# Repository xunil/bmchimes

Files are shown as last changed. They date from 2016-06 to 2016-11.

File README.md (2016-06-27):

Controller firmware for ESP8266 modules for Burning Man chimes project.

Using RtcDS3231 library https://github.com/Makuna/Rtc/

TODO:
* WiFi improvements
  * Add config keys for at least 3 WiFi networks and SSIDs
  * Attempt to join each in series for 20 seconds at a time
  * If all three fail, become AP instead
  * Add option to go straight to AP mode
* Add ADC measurement and recording for battery voltage
* Defaults for config

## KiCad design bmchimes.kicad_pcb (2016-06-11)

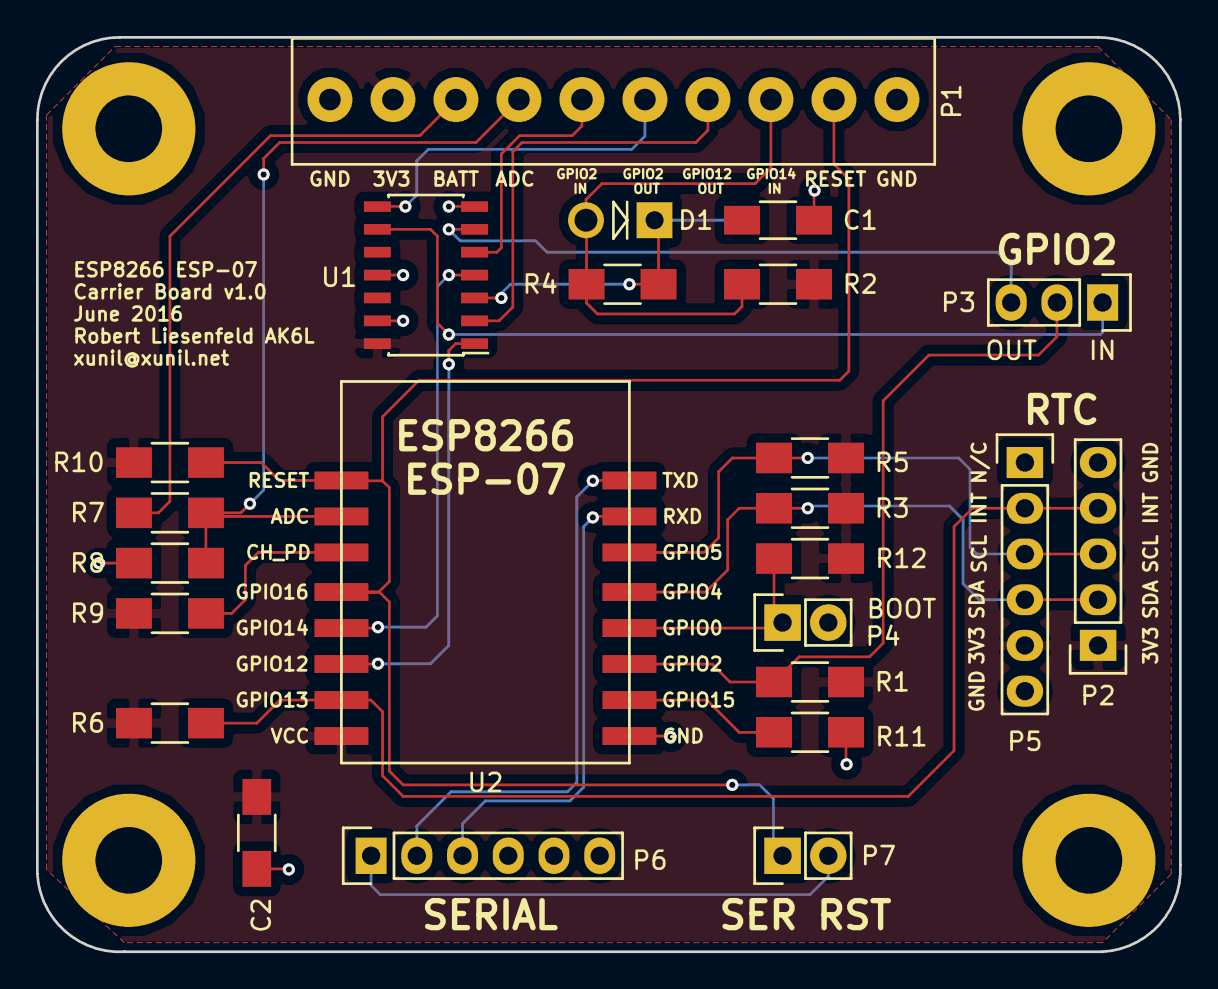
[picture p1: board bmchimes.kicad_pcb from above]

Board: 2 copper layers, 63.5 x 50.8 mm, 28 parts (0 on the bottom side), 24 nets.

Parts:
C1, C2: C; C_1206_HandSoldering
D1: D; Diode_DO-41_SOD81_Vertical_AnodeUp
P1: CONN_01X10; Adafruit_3.5mm_Terminal_Block
P2: CONN_01X05; Pin_Header_Straight_1x05
P3: CONN_02X03; Pin_Header_Straight_1x03
P4, P7: CONN_01X02; Pin_Header_Straight_1x02
P5, P6: CONN_01X06; Pin_Header_Straight_1x06
P8, P9, P10, P11: CONN_01X01; MountingHole_3.7mm_Pad
R1, R2, R3, R4, R5, R6, R7, R8, R9, R10, R11, R12: R; R_1206_HandSoldering
U1: 74HC7014; SOIC-14_3.9x8.7mm_Pitch1.27mm
U2: ESP07

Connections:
3V3: C2.1, P1.2, P2.1, P5.5, R1.1, R2.2, R3.1, R5.1, R6.1, R9.1, R10.1, R12.1, U1.14, U2.16
ADC: P1.4, R7.2, R8.1, U2.10
BATT: P1.3, R7.1
GND: C1.2, C2.2, P1.1, P1.10, P2.5, P4.2, P5.6, P6.6, P8.1, P9.1, P10.1, P11.1, R8.2, R11.2, U1.7, U1.11, U1.13, U2.1
GPIO2: P3.2, R1.2, U2.3
GPIO2_IN: P1.5, U1.5
GPIO2_IN_ST: P3.3, U1.6
GPIO2_OUT: P3.1, U1.9
GPIO2_OUT_ST: P1.6, U1.8
GPIO4: P2.2, P5.4, R3.2, U2.5
GPIO5: P2.3, P5.3, R5.2, U2.6
GPIO12: U1.1, U2.14
GPIO12_OUT: P1.7, U1.2
GPIO13: P2.4, P5.2, R6.2, U2.15
GPIO14: U1.4, U2.13
GPIO14_IN: D1.2, P1.8, R2.1, R4.2
GPIO14_IN_DB: C1.1, D1.1, R4.1, U1.3
unnamed: P4.1, R12.2, U2.4
unnamed: R9.2, U2.11
unnamed: R11.1, U2.2
RESET: P1.9, P7.1, R10.2, U2.9, U2.12
RESET_SER: P6.1, P7.2
RXD: P6.3, U2.7
TXD: P6.2, U2.8

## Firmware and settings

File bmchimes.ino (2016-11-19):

#include <ESP8266WiFi.h>
#include <WiFiClient.h>
#include <ESP8266mDNS.h>
#include <ESP8266SSDP.h>
#include <ESP8266WebServer.h>
#include <WiFiUdp.h>
#include <ArduinoOTA.h>
#include <Wire.h>
#include <time.h>
#include "FS.h"
#include <RtcDS3231.h>
#include <pgmspace.h>
#include "TeeSerial.h"
#include "StringStream.h"

// Uncomment to enable 15 minute chime, comment #undef below
// #define FIFTEEN_MINUTE_CHIME 1
// Disable 15-minute chime
#undef FIFTEEN_MINUTE_CHIME
// Uncomment to enable initial chimes, comment #undef below
// #define STRIKE_INITIAL_CHIMES 1
// Disable initial chime (used when chimes were installed around the man)
#undef STRIKE_INITIAL_CHIMES

// Allows streaming output (<< syntax)
template<class T> inline Print &operator <<(Print &obj, T arg) { obj.print(arg); return obj; }

const int heartbeatPin = 2;
const int rtcAlarmPin = 13;
const int chimePin = 12;
const int chimeStopSwitchPin = 14;
const int statsInterval = 1;
const int statsLinesPerDay = 24 * (60 / statsInterval);

struct BMChimeConfig {
  String deviceDescription;
  String wiFiSSID;
  String wiFiPassword;
  // From ESP8266WiFi.h
  WiFiMode wiFiMode;
  bool connectWiFiAtReset;
  bool sleepEnabled;
  uint16_t wakeEveryNSeconds;
  uint16_t stayAwakeSeconds;
  uint16_t chimeEveryNSeconds; 
  uint16_t chimeStopTimeout; 
  uint16_t chimeCount;
  uint16_t chimeNumber;
  uint16_t chimeCycleSeconds;
  uint16_t chimeInterInitialSeconds;
  bool chimeEnabled;
  bool heartbeatEnabled;
} config;

char ssid[64];
char password[64];
const int led = 2;

RtcDS3231 Rtc;
ESP8266WebServer server(80);

uint16_t sleepDuration = 0;
RtcDateTime wakeAlarmDateTime;
RtcDateTime sleepAlarmDateTime;
RtcDateTime chimeAlarmDateTime;
uint32_t chimeStartMillis = 0;
uint32_t chimeStopMillis = 0;
uint16_t lastChimeDurationMillis = 0;

bool chiming = false;
#define CHIME_INITIAL 0
#define CHIME_SECOND 1
#define CHIME_THIRD 2
#define CHIME_HOUR 3
#define NUM_CHIME_STATES 4
#define MAX_CHIME_SCHEDULE 15
#define INVALID_TIME 0xffffffff
time_t chimeSchedule[MAX_CHIME_SCHEDULE];

bool shouldCollectStats = false;
volatile bool chimingWasEnabled = false;
volatile bool chimeStopSwitchFlag = false;
volatile bool alarmInterruptFlag = false;

const int heartbeatBlipDuration = 50; // In milliseconds
const int heartbeatBlipInterval = 5 * 1000; // In milliseconds
uint32_t millisAtHeartbeatReset;
uint32_t millisAtLastHeartbeatBlip;
uint8_t heartbeatBlipCount = 0;
int heartbeatPinState = LOW;
uint8_t heartbeatBlipMax = 2 * 2; // 2 blinks - on, off, on, off, hence the multiply by 2

// Utility functions
void alarmISR() {
  alarmInterruptFlag = true;
}

void chimeStopSwitchISR() {
  chimeStopSwitchFlag = true;
}

void printStringAsHexDump(String str) {
  char buf[64];
  str.toCharArray(buf, 64);
  for (int i = 0; i < str.length(); i++) {
    TeeSerial0.print(buf[i], HEX);
    TeeSerial0 << " ";
  }
}

void printlnStringAsHexDump(String str) {
  printStringAsHexDump(str);
  TeeSerial0 << "\n";
}

void dateTimeStringFromRtcDateTime(RtcDateTime rtcDateTime, String& dateTimeBuf) {
  char datestring[20];
  snprintf_P(datestring, 
    20,
    PSTR("%02u/%02u/%04u %02u:%02u:%02u"),
    rtcDateTime.Month(),
    rtcDateTime.Day(),
    rtcDateTime.Year(),
    rtcDateTime.Hour(),
    rtcDateTime.Minute(),
    rtcDateTime.Second()
  );

  dateTimeBuf = String(datestring);
}

void getRtcDateTimeString(String& dateTimeBuf) {
  RtcDateTime now = Rtc.GetDateTime();
  dateTimeStringFromRtcDateTime(now, dateTimeBuf);
}

void getNtpDateTimeString(String& dateTimeBuf) {
  struct tm *tmp;
  time_t systemTime = time(nullptr);
  tmp = localtime(&systemTime);

  RtcDateTime systemRtcDateTime = RtcDateTime(
    tmp->tm_year + 1900,
    tmp->tm_mon + 1,
    tmp->tm_mday,
    tmp->tm_hour,
    tmp->tm_min,
    tmp->tm_sec
  );
  dateTimeStringFromRtcDateTime(systemRtcDateTime, dateTimeBuf);
}

uint16_t secondsTilNextN(uint16_t N, RtcDateTime &startingFrom) {
  // 16 bit return value should be sufficient; we will chime or wake at least once an hour.
  uint16_t seconds = ((N - (startingFrom.Minute() % N)) - 1) * 60;
  seconds += 60 - startingFrom.Second();

  return seconds;
}

bool alarmFired(DS3231AlarmFlag& flag) {
  bool wasAlarmed = false;
  if (alarmInterruptFlag) { // check our flag that gets sets in the interrupt
    wasAlarmed = true;
    alarmInterruptFlag = false; // reset the flag

    // this gives us which alarms triggered and
    // then allows for others to trigger again
    flag = Rtc.LatchAlarmsTriggeredFlags();
  }
  return wasAlarmed;
}

void chimeMotorOn() {
  digitalWrite(chimePin, HIGH);
}

void chimeMotorOff() {
  digitalWrite(chimePin, LOW);
}

void startChiming() {
  if (config.chimeEnabled) {
    TeeSerial0 << "Chiming!\n";
    // Set a flag indicating chiming has begun
    chiming = true;
    chimeStopSwitchFlag = false;
    // Store time chiming began
    chimeStartMillis = millis();
    // Trigger chime GPIO
    chimeMotorOn();
  } else {
    TeeSerial0 << "Chiming disabled (but would chime now)...\n";
  }
}

void stopChiming() {
  chimeStopMillis = millis();
  chimeMotorOff();
  chiming = false;
  lastChimeDurationMillis = chimeStopMillis - chimeStartMillis;
}

void heartbeatReset() {
  millisAtHeartbeatReset = millis();
  millisAtLastHeartbeatBlip = 0;
  heartbeatBlipCount = 0;
  heartbeatPinState = LOW;
  digitalWrite(heartbeatPin, heartbeatPinState);
}

void heartbeat() {
  // There's scratches all around the coin slot
  // Like a heartbeat, baby, trying to wake up
  // But this machine can only swallow money
  // You can't lay a patch by computer design
  // It's just a lot of stupid, stupid signs
  if (heartbeatBlipCount < heartbeatBlipMax) {
    uint32_t millisNow = millis();
    uint32_t millisDelta = millisNow - millisAtHeartbeatReset;
    if (millisDelta % heartbeatBlipDuration == 0 && millisAtLastHeartbeatBlip != millisNow) {
      millisAtLastHeartbeatBlip = millisNow;
      if (heartbeatPinState == LOW) {
        heartbeatPinState = HIGH;
      } else {
        heartbeatPinState = LOW;
      }
      digitalWrite(heartbeatPin, heartbeatPinState);
      heartbeatBlipCount++;
    }
  }
}


// Web server handler functions

void handleRoot() {
  RtcTemperature dieTemp = Rtc.GetTemperature();
  float dieTempF = (dieTemp.AsFloat()*(9.0/5.0))+32.0;

  String rtcDateTimeStr;
  getRtcDateTimeString(rtcDateTimeStr);
  String sleepAlarmDateTimeString;
  String chimeAlarmDateTimeString;
  dateTimeStringFromRtcDateTime(sleepAlarmDateTime, sleepAlarmDateTimeString);
  dateTimeStringFromRtcDateTime(chimeAlarmDateTime, chimeAlarmDateTimeString);

  String html = "<html>\n<head>\n";
  StringStream message = StringStream(html);
  message << "<title>" << config.deviceDescription << " - Chimes Controller</title>\n";
  message << "<style>form { display: inline; }</style>\n";
  message << "</head>\n<body>\n";
  message << "<h1>";
  message << config.deviceDescription;
  message << "</h1>\n";
  message << "<h2>Status</h2>\n";
  message << "This is chime #" << config.chimeNumber << " of " << config.chimeCount << "<br/>\n";
  message << "RTC date and time " << rtcDateTimeStr << "<br/>\n";
  message << "RTC die temperature " << dieTempF << "&deg;F<br/>\n";
  if (config.sleepEnabled) {
    message << "Next sleep scheduled at " << sleepAlarmDateTimeString << "<br/>\n";
  } else {
    message << "Sleep disabled, no sleep scheduled<br/>\n";
  }
  message << "Next chime scheduled at " << chimeAlarmDateTimeString << "<br/>\n";
  message << "Free heap: " << ESP.getFreeHeap() << " bytes<br/>\n";
  message << "Last chime stop switch interval: " << lastChimeDurationMillis << " milliseconds<br/>\n";
  if (WiFi.status() == WL_CONNECTED) {
    message << "Connected to WiFi network " << WiFi.SSID() << "<br/>\n";
  }

  message << "<table>\n";
  message << "<tr>\n";
  message << "<th>Chime Schedule</th>\n";
  message << "<th>Debug Log</th>\n";
  message << "</tr>\n";

  // Chime schedule
  message << "<tr>\n";
  message << "<td>\n";
  for (int i = 0; i < MAX_CHIME_SCHEDULE; i++) {
    RtcDateTime scheduledChimeDateTime = RtcDateTime();
    if (chimeSchedule[i] != 0xffffffff) {
      scheduledChimeDateTime.InitWithEpoch32Time(chimeSchedule[i]);
      String scheduledChimeString;
      dateTimeStringFromRtcDateTime(scheduledChimeDateTime, scheduledChimeString);
      message << scheduledChimeString << "<br/>\n";
    }
  }
  message << "</td>\n";

  // Debug log
  String debugLog;
  yield();
  TeeSerial0.getBuffer(debugLog);
  message << "<td>\n";
  message << "<pre>\n";
  message << debugLog;
  message << "</pre>\n";
  message << "</td>\n";
  message << "</tr>\n";

  // Buttons for the various actions
  message << "<tr>\n";
  message << "<td colspan=\"2\">\n";
  message << "<form action=\"/config\" method=\"get\"><input type=\"submit\" value=\"Configure\"/></form>\n";
  message << "<form action=\"/time\" method=\"get\"><input type=\"submit\" value=\"Manage Time\"/></form>\n";
  message << "<form action=\"/stats\" method=\"get\"><input type=\"submit\" value=\"Statistics\"/></form>\n";
  message << "<form action=\"/debuglog\" method=\"get\"><input type=\"submit\" value=\"Debug Log\"/></form>\n";
  message << "<form action=\"/sleep\" method=\"get\"><input type=\"submit\" value=\"Sleep Now\"/></form>\n";
  message << "<form action=\"/chimenow\" method=\"get\"><input type=\"submit\" value=\"Chime Now\"/></form>\n";
  message << "<form action=\"/reset\" method=\"get\"><input type=\"submit\" value=\"Reset\"/></form>\n";
  message << "</td>\n";
  message << "</tr>\n";
  message << "</table>\n";
  message << "</body>\n</html>\n";

  server.send(200, "text/html", html);
}

void handleSleep() {
  String message = "<html>\n<head>\n\t<title>Sleep</title>\n</head>\n<body>\n";
  message += "<h1>Not yet implemented</h1>\n";
  message += "<form action=\"/\" method=\"post\"><input type=\"submit\" value=\"Home\"/></form>\n";
  message += "</body>\n</html>\n";
  
  server.send(200, "text/html", message);
}

void handleReset() {
  String message = "<html>\n<head>\n";
  message += "<title>";
  message += config.deviceDescription;
  message += " - Reset</title>\n</head>\n<body>\n";
  message += "<h1>Resetting!</h1>";
  message += "</body>\n</html>\n";
  
  server.sendHeader("Refresh", "20; url=/");
  server.send(200, "text/html", message);
  delay(2000);
  ESP.restart();
}

void handleTemp() {
  RtcTemperature dieTemp = Rtc.GetTemperature();
  float dieTempF = (dieTemp.AsFloat()*(9.0/5.0))+32.0;
  
  String message = "<html>\n<head>\n";
  message += "<title>";
  message += config.deviceDescription;
  message += " - Temperature</title>\n</head>\n<body>\n";
  message += "<h1>Die temperature ";
  message += dieTempF;
  message += "&deg;F</h1>\n";
  message += "<form action=\"/\" method=\"post\"><input type=\"submit\" value=\"Home\"/></form>\n";
  message += "</body>\n</html>\n";
  
  server.send(200, "text/html", message);
}

void handleTime() {
  String message = "<html>\n<head>\n";
  message += "<title>";
  message += config.deviceDescription;
  message += " - Manage Time</title>\n</head>\n<body>\n";
  message += "<h1>Time</h1>\n";
  if (server.method() == HTTP_POST) {
    for (uint8_t i = 0; i < server.args(); i++) {
      if (server.argName(i) == "writeNTP") {
        syncNTPTime();
        writeNtpTimeToRtc();
        // Schedule next chime
        calculateSleepAndChimeTiming();
        setRtcAlarms();
        message += "<h2>Wrote NTP time to RTC</h2>\n";
      }
    }
  }

  String rtcDateTimeStr;
  String ntpDateTimeStr;
  getRtcDateTimeString(rtcDateTimeStr);
  getNtpDateTimeString(ntpDateTimeStr);

  message += "RTC date and time ";
  message += rtcDateTimeStr;
  message += "<br/>\n";
  message += "NTP date and time ";
  message += ntpDateTimeStr;
  message += "<br/>\n";
  message += "<form action=\"/time\" method=\"post\">\n";
  message += "<input type=\"submit\" value=\"Sync with NTP and write to RTC\"/>\n";
  message += "<input type=\"hidden\" name=\"writeNTP\" value=\"true\"/>\n";
  message += "</form>\n";
  message += "<form action=\"/\" method=\"post\"><input type=\"submit\" value=\"Home\"/></form>\n";
  message += "</body>\n</html>\n";

  server.send(200, "text/html", message);
}

void handleConfig() {
  String html = "<html>\n<head>\n";
  StringStream message = StringStream(html);
  message << "<title>";
  message << config.deviceDescription;
  message << " - Configuration</title>\n";
  message << "<style>\n";
  message << "label { font-weight: bold; display: block; width: 200px; float: left; }\n";
  message << "form { display: inline; }\n";
  message << "</style>\n";
  message << "</head>\n<body>\n";
  message << "<h1>Configuration</h1>";

  if (server.method() == HTTP_POST) {
    // User selected save
    // Checkbox form elements are not passed in the POST unless they are checked;
    // therefore, assume they are unchecked and let the for loop below correct this
    config.sleepEnabled = false;
    config.connectWiFiAtReset = false;
    config.chimeEnabled = false;
    config.heartbeatEnabled = false;

    for (uint8_t i = 0; i < server.args(); i++) {
      String argName = String(server.argName(i));
      String argValue = String(server.arg(i));
      TeeSerial0 << "handleConfig(): argName = " << argName << "; argValue = " << argValue << "\n";

      if (argName == "DeviceDescription") {
        TeeSerial0 << "Setting Device Description " << argValue << "\n";
        config.deviceDescription = argValue;
      } else if (argName == "WiFiSSID") {
        TeeSerial0 << "Setting WiFi SSID " << argValue << "\n";
        config.wiFiSSID = argValue;
      } else if (argName == "WiFiPassword") {
        TeeSerial0 << "Setting WiFi password " << argValue << "\n";
        config.wiFiPassword = argValue;
      } else if (argName == "WiFiMode") {
        // Either Station or AP
        TeeSerial0 << "Setting WiFi mode " << argValue << "\n";
        argValue.toUpperCase(); if (argValue == "AP") {
          config.wiFiMode = WIFI_AP;
        } else if (argValue == "STATION") {
          config.wiFiMode = WIFI_STA;
        } else {
          TeeSerial0 << "Unknown WiFi mode " << argValue << "; defaulting to STATION\n";
          config.wiFiMode = WIFI_STA;
        }
      } else if (argName == "ConnectWiFiAtReset") {
        // true or false
        TeeSerial0 << "Setting connect WiFi at reset flag to " << argValue << "\n";
        argValue.toUpperCase();
        if (argValue == "TRUE" || argValue == "ON") {
          config.connectWiFiAtReset = true;
        } else if (argValue == "FALSE" || argValue == "OFF") {
          config.connectWiFiAtReset = false;
        } else {
          TeeSerial0 << "Unknown boolean value " << argValue << "; defaulting to TRUE\n";
          config.connectWiFiAtReset = true;
        }
      } else if (argName == "SleepEnabled") {
        // true or false
        TeeSerial0 << "Setting sleep enabled flag to " << argValue << "\n";
        argValue.toUpperCase();
        if (argValue == "TRUE" || argValue == "ON") {
          config.sleepEnabled = true;
        } else if (argValue == "FALSE" || argValue == "OFF") {
          config.sleepEnabled = false;
        } else {
          TeeSerial0 << "Unknown boolean value " << argValue << "; defaulting to TRUE\n";
          config.sleepEnabled = true;
        }
      } else if (argName == "WakeEveryNSeconds") {
        TeeSerial0 << "Setting wake every N to " << argValue << "\n";
        config.wakeEveryNSeconds = argValue.toInt();
      } else if (argName == "StayAwakeSeconds") {
        TeeSerial0 << "Setting stay awake time to " << argValue << "\n";
        config.stayAwakeSeconds = argValue.toInt();
      } else if (argName == "ChimeEveryNSeconds") {
        TeeSerial0 << "Setting chime every N to " << argValue << "\n";
        config.chimeEveryNSeconds = argValue.toInt();
      } else if (argName == "ChimeStopTimeout") {
        if (argValue.toInt() > 65535) {
          TeeSerial0 << "Value " << argValue << " larger than maximum 65535. Limiting to 65535.\n";
          config.chimeStopTimeout = 65535;
        } else {
          TeeSerial0 << "Setting chime stop timeout to " << argValue << "\n";
          config.chimeStopTimeout = argValue.toInt();
        }
      } else if (argName == "ChimeNumber") {
        TeeSerial0 << "Setting chime number to " << argValue << "\n";
        config.chimeNumber = argValue.toInt();
      } else if (argName == "ChimeCount") {
        TeeSerial0 << "Setting chime count to " << argValue << "\n";
        config.chimeCount = argValue.toInt();
      } else if (argName == "ChimeCycleSeconds") {
        TeeSerial0 << "Setting chime cycle seconds to " << argValue << "\n";
        config.chimeCycleSeconds = argValue.toInt();
      } else if (argName == "ChimeInterInitialSeconds") {
        TeeSerial0 << "Setting chime inter-initial seconds to " << argValue << "\n";
        config.chimeInterInitialSeconds = argValue.toInt();
      } else if (argName == "ChimeEnabled") {
        // true or false
        TeeSerial0 << "Setting chime enabled flag to " << argValue << "\n";
        argValue.toUpperCase();
        if (argValue == "TRUE" || argValue == "ON") {
          config.chimeEnabled = true;
        } else if (argValue == "FALSE" || argValue == "OFF") {
          config.chimeEnabled = false;
        } else {
          TeeSerial0 << "Unknown boolean value " << argValue << "; defaulting to TRUE\n";
          config.chimeEnabled = true;
        }
      } else if (argName == "HeartbeatEnabled") {
        // true or false
        TeeSerial0 << "Setting heartbeat enabled flag to " << argValue << "\n";
        argValue.toUpperCase();
        if (argValue == "TRUE" || argValue == "ON") {
          config.heartbeatEnabled = true;
        } else if (argValue == "FALSE" || argValue == "OFF") {
          config.heartbeatEnabled = false;
        } else {
          TeeSerial0 << "Unknown boolean value " << argValue << "; defaulting to TRUE\n";
          config.heartbeatEnabled = true;
        }
      } else {
        TeeSerial0 << "Unknown configuration key " << argName << "\n";
      }
    }

    // Write updated configuration to SPIFFS
    // But don't bother if this was just an empty POST
    if (server.args() > 0) {
      writeConfig();
      message << "<h4>Configuration updated.</h4>\n";
    }
  }
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
void loop(void) {
  String nowString;
  DS3231AlarmFlag flag;

  // Probably unnecessary, but doesn't hurt anything.
  yield();

  if (config.heartbeatEnabled && millis() % heartbeatBlipInterval == 0) {
    heartbeatReset();
  }

  if (alarmFired(flag)) {
    RtcDateTime now = Rtc.GetDateTime();
    if (flag & DS3231AlarmFlag_Alarm1) {
      // Chime alarm fired
      TeeSerial0 << "Chime alarm fired!\n";
      dateTimeStringFromRtcDateTime(now, nowString);
      TeeSerial0 << "Time is now " << nowString << "\n";
      if (!chiming) {
        startChiming();
      } else {
        // Hopefully we only get here if someone has triggered a manual chime.
        TeeSerial0 << "Chiming already in progress, skipping scheduled chime.\n";
      }
    }

    if (flag & DS3231AlarmFlag_Alarm2) {
      // Once-per-minute alarm fired
      if (config.sleepEnabled
            && sleepAlarmDateTime.Hour() == now.Hour()
            && sleepAlarmDateTime.Minute() == now.Minute()
            && sleepAlarmDateTime.Second() == now.Second()) {
        // sleep now
        dateTimeStringFromRtcDateTime(now, nowString);
        TeeSerial0 << "Time is now " << nowString << "\n";
        if (sleepDuration == 0) {
          // Sanity check; if we sleep for 0 seconds, the ESP never wakes up.
          TeeSerial0 << "Sleep duration is zero, skipping sleep.\n";
        } else {
          TeeSerial0 << "Sleeping for " << sleepDuration << " seconds\n";
          // deepSleep expects a number in microseconds
          ESP.deepSleep(sleepDuration * 1e6);
        }
      }

      // Collect statistics - this is time consuming, don't do it while chiming.
      // Instead, set a flag.  Timing of stats collection is far from critical.
      if (now.Minute() % statsInterval == 0) {
        shouldCollectStats = true;
      }

      // Update chime schedule
      scheduleNextChime(now);

#ifdef FIFTEEN_MINUTE_CHIME
      // Single strike at the 15 minute mark, unless it would overlap with the chime schedule
      if (now.Minute() % 15 == 0) {
        fifteenMinuteChime(now);
      }
#endif
    }
  }

  // Check time every loop, turn off chime GPIO if timeout
  if (chiming) {
    // Check for stop conditions (timeout, stop switch)
    if (chimeStopSwitchFlag || (millis() - chimeStartMillis > config.chimeStopTimeout)) {
      // Check chime home switch GPIO flag (set by interrupt), turn off chime GPIO if set
      if (chimeStopSwitchFlag) {
        TeeSerial0 << "Chime stop switch activated, turning off chime motor\n";
      } else {
        TeeSerial0 << "Timeout waiting for chime stop switch activation!\n";
      }
      stopChiming();
      RtcDateTime now = Rtc.GetDateTime();
      scheduleNextChime(now);
    }
  } else {
    if (shouldCollectStats) {
      collectStats();
      shouldCollectStats = false;
    }
  }
  
  server.handleClient();
  ArduinoOTA.handle();

  if (config.heartbeatEnabled) {
    heartbeat();
  }
}

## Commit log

2016-03-29 Switched to Rtc library from https://github.com/Makuna/Rtc
2016-04-08 Config read from SPIFFS working
    [example.cfg]
2016-04-10 Added config write, status page, reset button
2016-04-11 Added device description field, chime offset field, home buttons; reset page now refreshes automatically
    [example.cfg]
2016-04-15 WIP: Still trying to figure out wake/sleep cycle timing
    [example.cfg]
2016-05-10 Finishing up this branch, which has incorporated far more than just config parsing.
    [example.cfg]
2016-05-24 Chime timing and stop switch detection is working.
    [example.cfg]
2016-05-25 Fixed bug in handleConfig with handling of checkboxes.
    [bmchimes.ino]
2016-05-30 First effort at a carrier board for the ESP07.
    [bmchimes.kicad_pcb, bmchimes.sch]
2016-06-01 Added buffer chip to schematic
    [bmchimes.sch]
2016-06-04 ERC passes
    [bmchimes.sch]
2016-06-04 WIP: Pin header layout
    [bmchimes.sch]
2016-06-06 Reworked some of the pull-ups and re-annotated.
    [bmchimes.sch]
2016-06-07 Added footprint for ESP07
2016-06-09 Basic layout complete, ground and power zones defined.
    [bmchimes.kicad_pcb, bmchimes.sch]
2016-06-10 Zero unconnected nets, calling it done
    [bmchimes.kicad_pcb]
2016-06-11 Silkscreen changes, sent board to OSH Park
    [bmchimes.kicad_pcb]
2016-06-15 Added values, ordered parts
    [bmchimes.sch]
2016-06-27 Switched back to chimes being triggered by an RTC alarm; still need to add chime repetition and hours chiming; sleeping and stats collection triggered by once-per-minute alarm.
2016-07-01 Many fixes and features: - Separated chiming back onto its own alarm. - Added chime testing page. - Added default config when config not found on SPIFFS. - Added WiFi AP mode. - Default configuration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
    [bmchimes.ino]
2016-07-01 Minor fixes to debug output; added logic to skip a scheduled chime if a manual one is in progress; fixed issue with AP mode.
    [bmchimes.ino]
2016-07-04 - Updated root page to display next chime, next sleep, and correct temperature. - Syncing with NTP and writing to RTC will now cause sleep and chime timing to be recalculated. - Added ability to clea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
    [bmchimes.ino]
2016-07-05 No idea why, but twiddling the LED in the stop switch ISR seems to have fixed the issue.
    [bmchimes.ino]
2016-07-06 Don't handle web requests while chiming as it interferes with interrupt response times, such as for the chime stop switch.
    [bmchimes.ino]
2016-07-06 Fixed statistics collection for chime duration.
    [bmchimes.ino]
2016-07-19 Turns out rewriting a 1400+ line file to slow flash takes about 5 or 6 seconds, so we just won't do that while chiming. Future enhancement: set a flag to collect stats, collect after chime finished.
    [bmchimes.ino]
2016-07-22 Removed some unnecessary headers, switched from #defines to consts, rearranged some header includes, and got the heartbeat working (sort of).
2016-07-23 Fixing stats collection bug
    [bmchimes.ino]
2016-07-31 Bugfixes and added configuration options, including: - Added config option to enable/disable heartbeat LED on pin 2 - Added config option for inter-chime delay, in preparation for sequential chime - 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
    [example.cfg]
2016-08-01 All timing in seconds (except for stop switch timeout, which is in ms), also added chime sequence and hour chime.
2016-08-02 Updating example config to reflect updated options
    [example.cfg]
2016-08-06 Switched to model where chime schedule is calculated ahead of time. Schedule is checked for validity when once-per-minute alarm fires, and if invalid, is recalculated. Still appear to have bugs with 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
    [bmchimes.ino]
2016-08-07 Enlarged TeeSerial buffer to 2 kilobytes; switched all debugging output to use streaming form (<<) rather than print/println calls. Added some debugging for stats collection.
2016-08-11 Added device description to page titles; added auto-refreshing page for debug log; more attempts at perfecting chime schedule calculation.
2016-08-14 WIP: Switching to scheduling algorithm with parameters of N chimes, M of N, and cycle interval.
2016-08-14 Ruby prototype for new scheduling algorithm
2016-08-14 Removed now-unused configuration elements, deleted a couple unused variables, removed the enum for chime state since it's not relevant outside of schedule calculation.
2016-08-15 Added parameters for chime N of M, put the stop switch interval on the front page, and added a ton of debug in the chime schedule function.
2016-08-17 Spelling error, and some debug code for the sleep time calculation.
    [bmchimes.ino]
2016-08-21 Reporting progress less often to avoid slowing down OTA update.
    [bmchimes.ino]
2016-08-21 Changed chime schedule algorithm to bring the initial chimes closer together, and to add a couple 'silent' strike intervals. Also exposed the chime number in the root page.
